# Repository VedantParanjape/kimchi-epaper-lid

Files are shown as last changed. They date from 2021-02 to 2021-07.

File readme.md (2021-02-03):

# kimχ micro lid KiCad project template

This template lets you create lid expansion boards for the [kimχ micro i.MX8M Mini SBC](https://labs.groupgets.com/kimchi-micro).

This project should include everything you need to make an expansion board, including an eeprom
that can be used to identify your lid and automatically load the correct configuration files (with
some software work to support this).

## How to use this project

This project is to be used with KiCad's "New Project from Template" function.

### Download with GitHub

On GitHub you can select Clone or Download -> Download Zip. Then expand the archive and move it into your user's KiCad templates directory: `$HOME/kicad/template/`. You may have to create this directory if it doesn't exist.

In KiCad, select File > New Project > New Project From Template, and select User Templates. You can then select the kimχ micro - LID project in this list.

### Clone with GitHub

Alternatively, you can create a new GitHub project from this template by selecting Use This Template, above. From there you clone the new project locally and open it directly with KiCad.

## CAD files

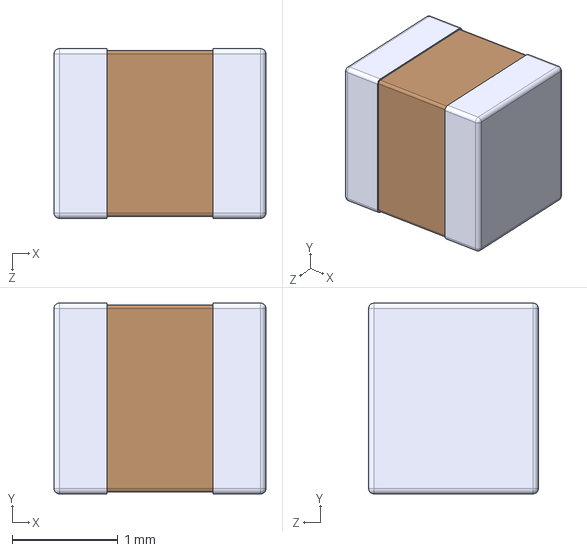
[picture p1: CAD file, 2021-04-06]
component-libraries/LBM2016T680J/LBM2016T680J.step
2.00 x 1.80 x 1.60 mm

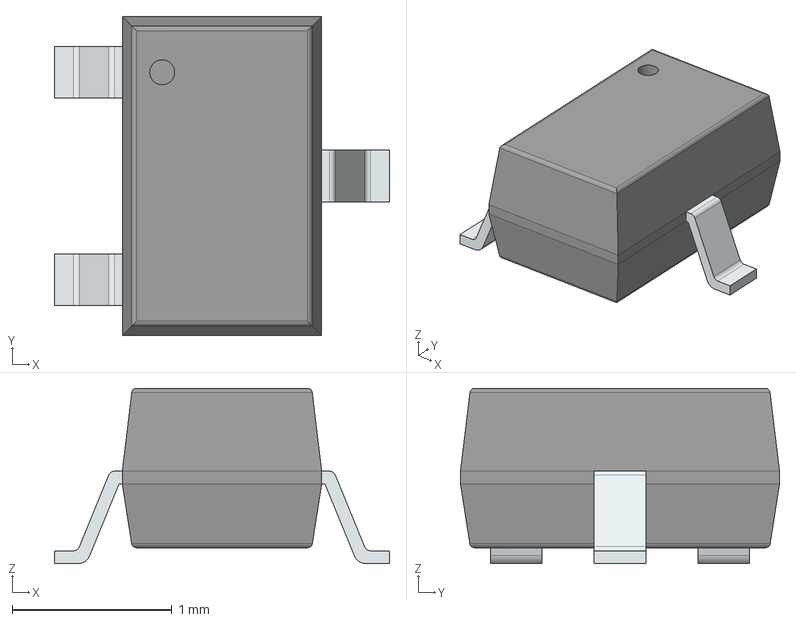
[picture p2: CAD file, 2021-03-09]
component-libraries/SI1308EDL-T1-BE3/SI1308EDL-T1-BE3.stp
2.10 x 2.00 x 1.10 mm
PinsArrayL
FilletPinR

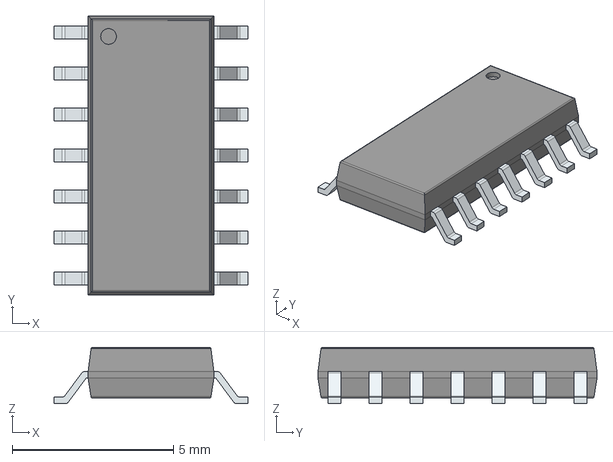
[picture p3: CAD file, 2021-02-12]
component-libraries/TXS0104ED/TXS0104ED.stp
6.00 x 8.65 x 1.75 mm
PinsArrayLR

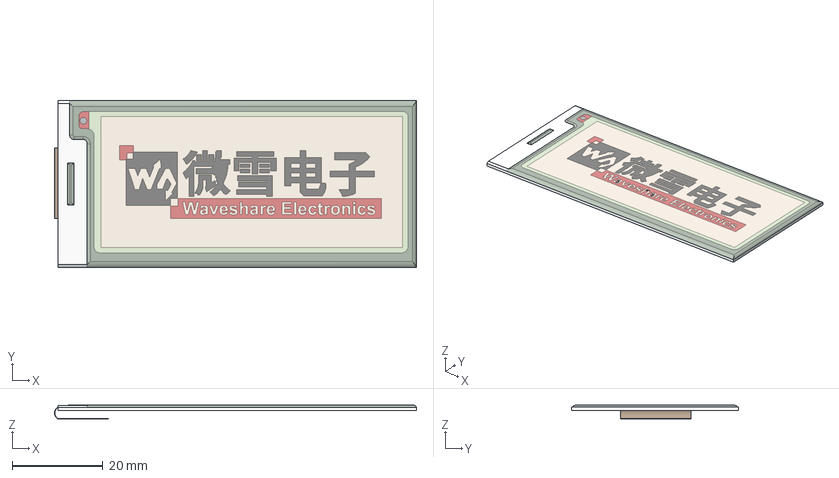
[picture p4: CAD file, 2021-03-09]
component-libraries/EPAPER_FPC_CONNECTOR/Waveshare 2.9 (B) E-ink - Display Folded.stp
79.9 x 36.8 x 3.17 mm

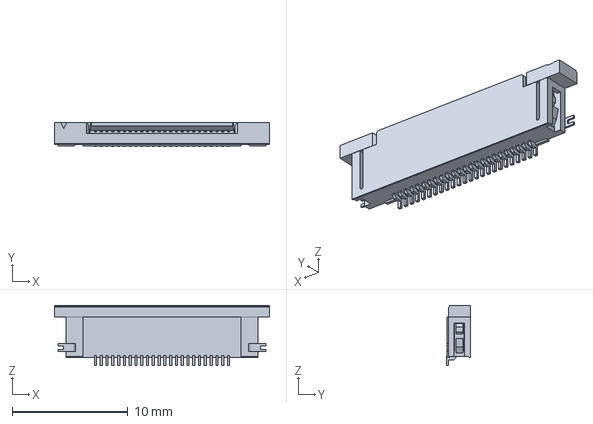
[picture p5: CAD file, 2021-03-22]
component-libraries/EPAPER_FPC_CONNECTOR/524352471.stp
18.6 x 2.05 x 5.20 mm

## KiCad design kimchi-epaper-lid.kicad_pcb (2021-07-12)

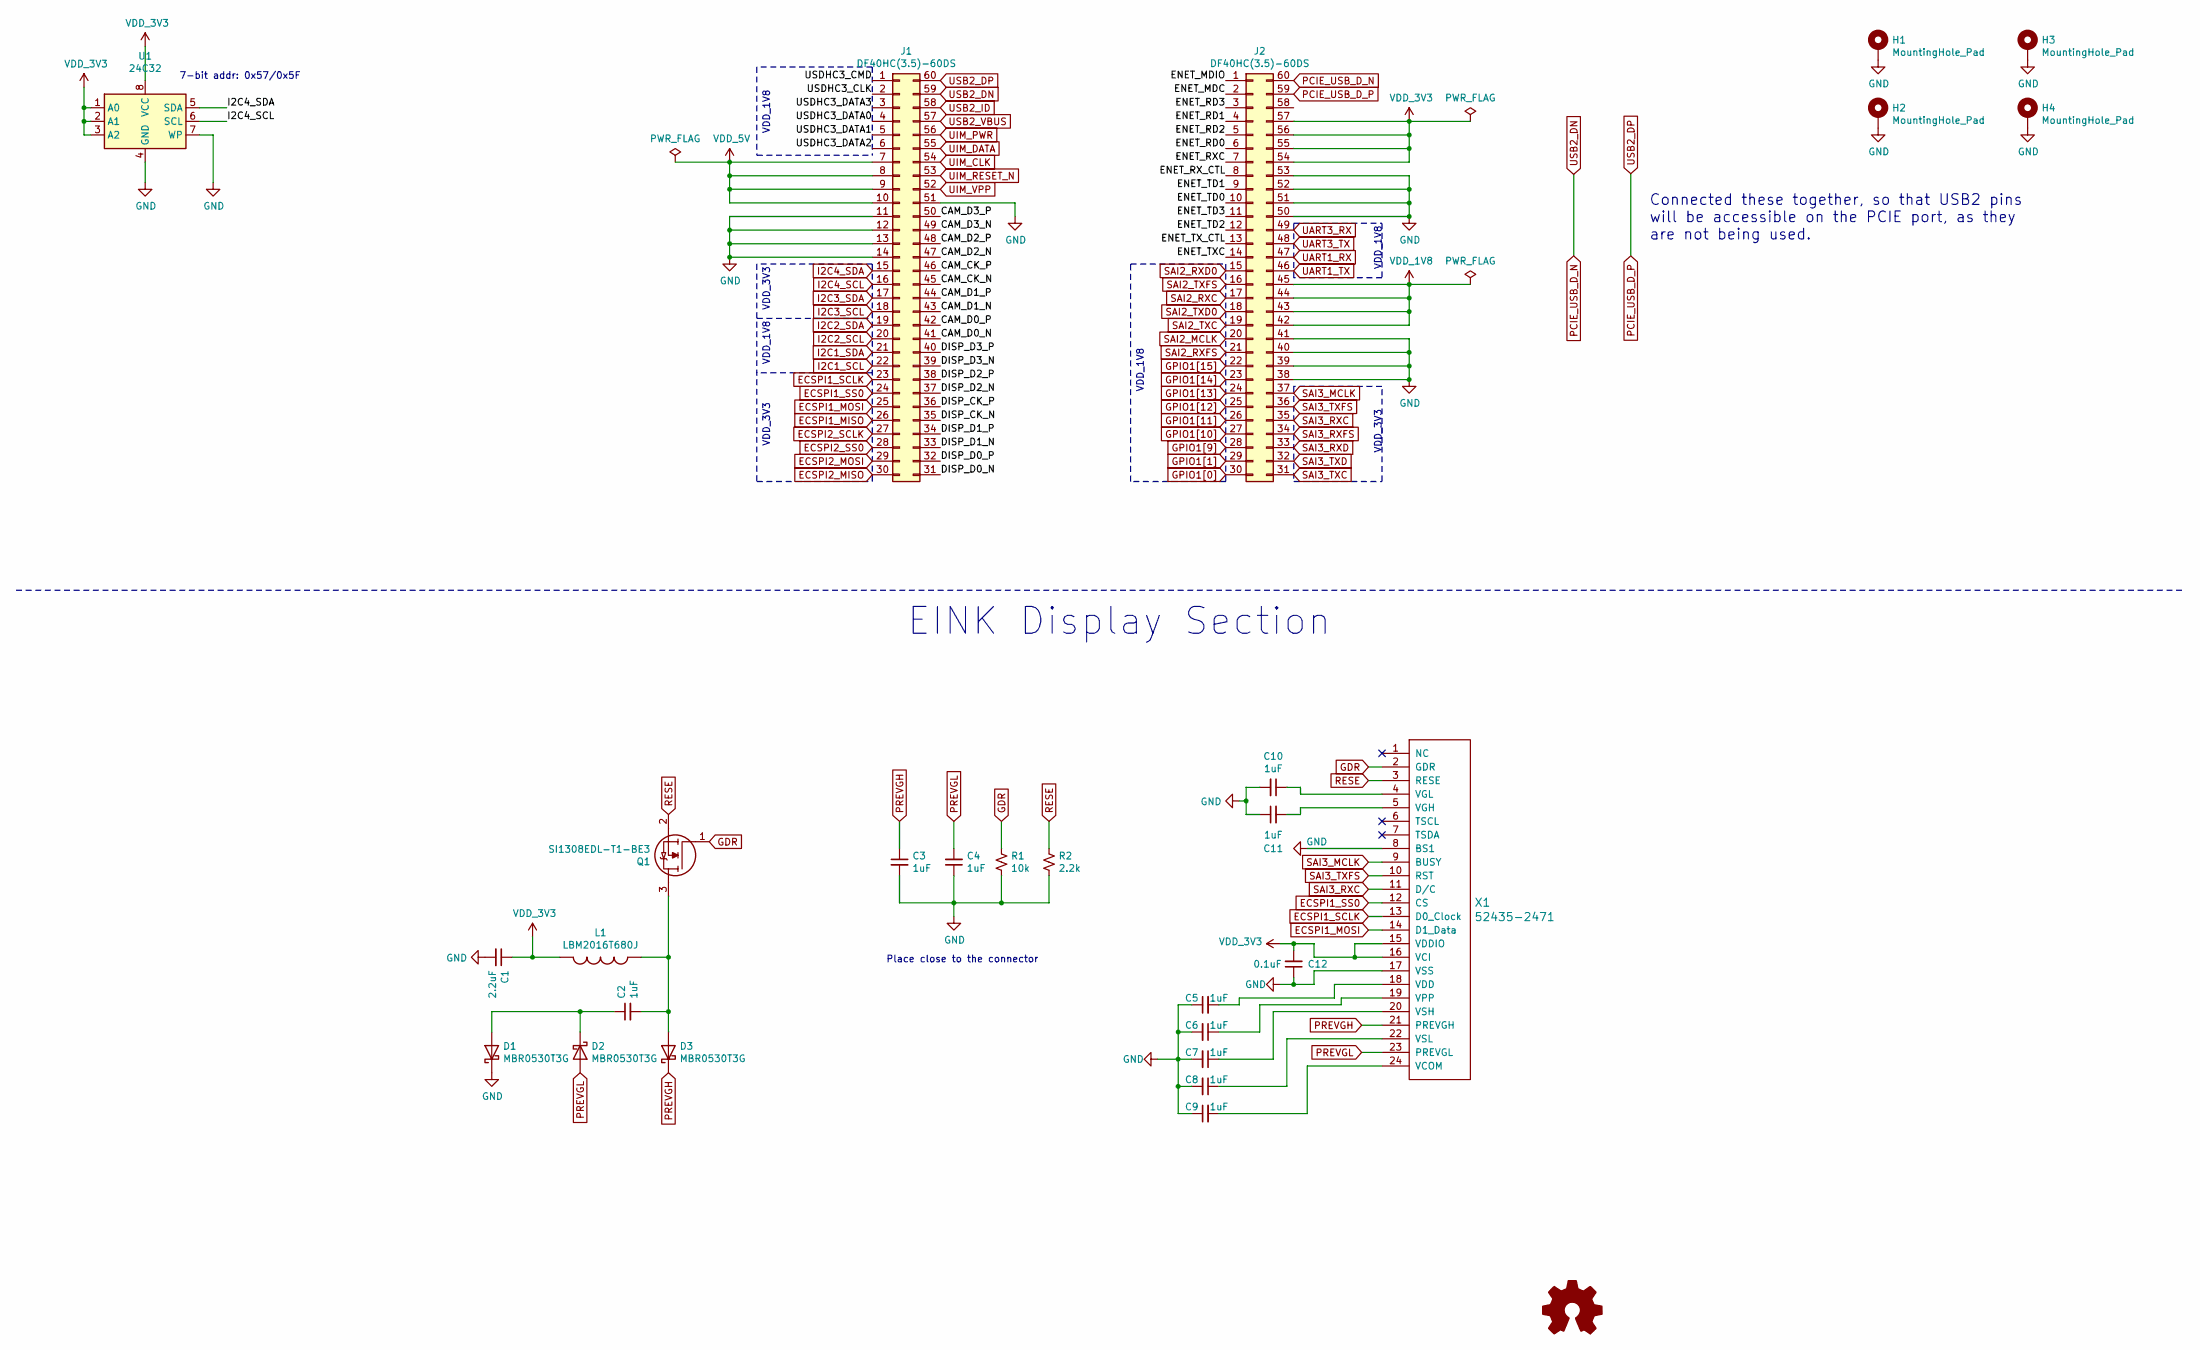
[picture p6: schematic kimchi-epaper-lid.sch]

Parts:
C1: 2.2uF; C_0603_1608Metric
C2, C3, C4, C5, C6, C7, C8, C9, C10, C11: 1uF; C_0603_1608Metric
C12: 0.1uF; C_0603_1608Metric
D1, D2, D3: MBR0530T3G; D_SOD-123
H1, H2, H3, H4: MountingHole_Pad; MountingHole_3mm_Pad
J1, J2: DF40HC(3.5)-60DS
L1: LBM2016T680J; INDC2016X180N
LOGO1: Logo_Open_Hardware_Small; OSHW-Logo_5.7x6mm_SilkScreen
Q1: SI1308EDL-T1-BE3; SOT65P210X110-3N; Manufacturer_Part_Number SI1308EDL-T1-BE3; Mouser Part Number 78-SI1308EDL-T1-BE3
R1: 10k; R_0603_1608Metric
R2: 2.2k; R_0603_1608Metric
U1: 24C32; DFN-8-1EP_3x2mm_P0.5mm_EP1.36x1.46mm; Part M24C32-FMC6TG
X1: 52435-2471; MOLEX_52435-2471

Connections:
/CAM_CK_N: J1.45
/CAM_CK_P: J1.46
/CAM_D0_N: J1.41
/CAM_D0_P: J1.42
/CAM_D1_N: J1.43
/CAM_D1_P: J1.44
/CAM_D2_N: J1.47
/CAM_D2_P: J1.48
/CAM_D3_N: J1.49
/CAM_D3_P: J1.50
/DISP_CK_N: J1.35
/DISP_CK_P: J1.36
/DISP_D0_N: J1.31
/DISP_D0_P: J1.32
/DISP_D1_N: J1.33
/DISP_D1_P: J1.34
/DISP_D2_N: J1.37
/DISP_D2_P: J1.38
/DISP_D3_N: J1.39
/DISP_D3_P: J1.40
/ENET_MDC: J2.2
/ENET_MDIO: J2.1
/ENET_RD0: J2.6
/ENET_RD1: J2.4
/ENET_RD2: J2.5
/ENET_RD3: J2.3
/ENET_RXC: J2.7
/ENET_RX_CTL: J2.8
/ENET_TD0: J2.10
/ENET_TD1: J2.9
/ENET_TD2: J2.12
/ENET_TD3: J2.11
/ENET_TXC: J2.14
/ENET_TX_CTL: J2.13
/USDHC3_CLK: J1.2
/USDHC3_CMD: J1.1
/USDHC3_DATA0: J1.4
/USDHC3_DATA1: J1.5
/USDHC3_DATA2: J1.6
/USDHC3_DATA3: J1.3
ECSPI1_MISO: J1.26
ECSPI1_MOSI: J1.25, X1.14 (D1_Data)
ECSPI1_SCLK: J1.23, X1.13 (D0_Clock)
ECSPI1_SS0: J1.24, X1.12 (CS)
ECSPI2_MISO: J1.30
ECSPI2_MOSI: J1.29
ECSPI2_SCLK: J1.27
ECSPI2_SS0: J1.28
GDR: Q1.1, R1.1, X1.2 (GDR)
GND: C1.2, C3.2, C4.1, C5.1, C6.2, C7.2, C8.2, C9.1, C10.2, C11.1, C12.1, D1.1 (K), H1.1, H2.1, H3.1, H4.1, J1.11, J1.12, J1.13, J1.14, J1.51, J2.38, J2.39, J2.40, J2.41, J2.50, J2.51, J2.52, J2.53, R1.2, R2.2, U1.4 (GND), U1.7 (WP), X1.8 (BS1), X1.17 (VSS)
GPIO1[0]: J2.30
GPIO1[1]: J2.29
GPIO1[9]: J2.28
GPIO1[10]: J2.27
GPIO1[11]: J2.26
GPIO1[12]: J2.25
GPIO1[13]: J2.24
GPIO1[14]: J2.23
GPIO1[15]: J2.22
I2C1_SCL: J1.22
I2C1_SDA: J1.21
I2C2_SCL: J1.20
I2C2_SDA: J1.19
I2C3_SCL: J1.18
I2C3_SDA: J1.17
I2C4_SCL: J1.16, U1.6 (SCL)
I2C4_SDA: J1.15, U1.5 (SDA)
unnamed: C2.1, D1.2 (A), D2.1 (K)
unnamed: C2.2, D3.2 (A), L1.2, Q1.3
unnamed: C5.2, X1.18 (VDD)
unnamed: C6.1, X1.19 (VPP)
unnamed: C7.1, X1.20 (VSH)
unnamed: C8.1, X1.22 (VSL)
unnamed: C9.2, X1.24 (VCOM)
unnamed: C10.1, X1.4 (VGL)
unnamed: C11.2, X1.5 (VGH)
PCIE_USB_D_N: J1.59, J2.60
PCIE_USB_D_P: J1.60, J2.59
PREVGH: C3.1, D3.1 (K), X1.21 (PREVGH)
PREVGL: C4.2, D2.2 (A), X1.23 (PREVGL)
RESE: Q1.2, R2.1, X1.3 (RESE)
SAI2_MCLK: J2.20
SAI2_RXC: J2.17
SAI2_RXD0: J2.15
SAI2_RXFS: J2.21
SAI2_TXC: J2.19
SAI2_TXD0: J2.18
SAI2_TXFS: J2.16
SAI3_MCLK: J2.37, X1.9 (BUSY)
SAI3_RXC: J2.35, X1.11 (D/C)
SAI3_RXD: J2.33
SAI3_RXFS: J2.34
SAI3_TXC: J2.31
SAI3_TXD: J2.32
SAI3_TXFS: J2.36, X1.10 (RST)
UART1_RX: J2.47
UART1_TX: J2.46
UART3_RX: J2.49
UART3_TX: J2.48
UIM_CLK: J1.54
UIM_DATA: J1.55
UIM_PWR: J1.56
UIM_RESET_N: J1.53
UIM_VPP: J1.52
USB2_ID: J1.58
USB2_VBUS: J1.57
VDD_1V8: J2.42, J2.43, J2.44, J2.45
VDD_3V3: C1.1, C12.2, J2.54, J2.55, J2.56, J2.57, L1.1, U1.1 (A0), U1.2 (A1), U1.3 (A2), U1.8 (VCC), X1.15 (VDDIO), X1.16 (VCI)
VDD_5V: J1.7, J1.8, J1.9, J1.10

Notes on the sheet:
7-bit addr: 0x57/0x5F
VDD_1V8
VDD_3V3
EINK Display Section
Place close to the connector
Connected these together, so that USB2 pins will be accessible on the PCIE port, as they are not being used.

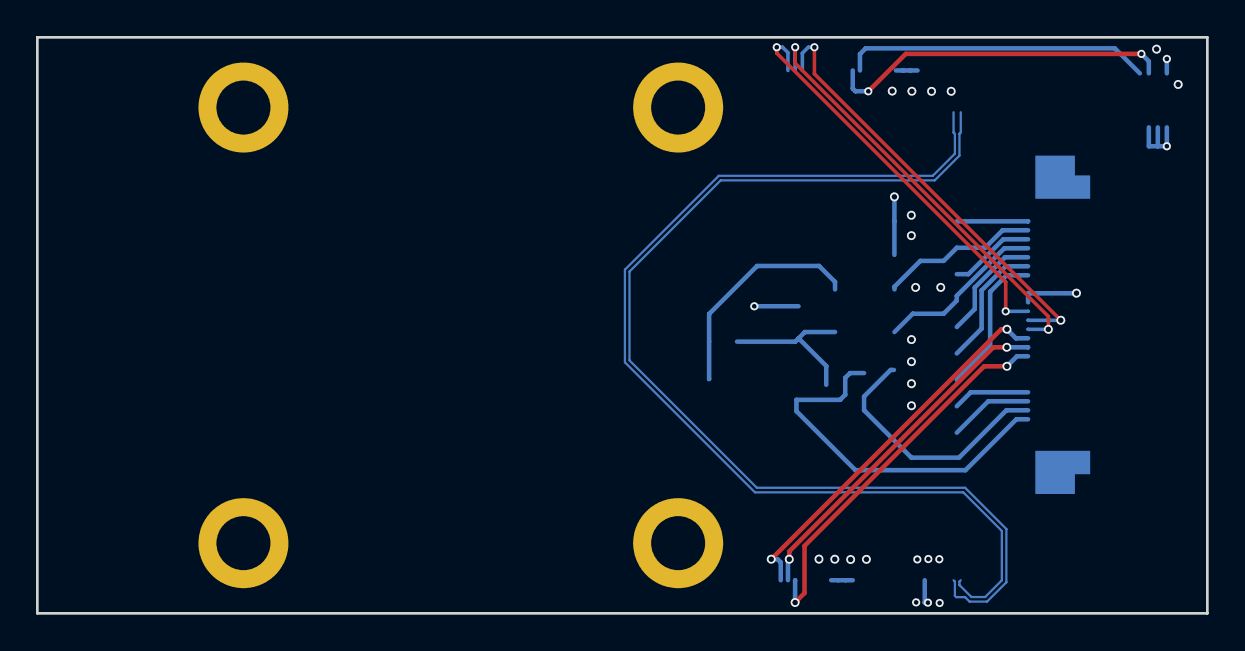
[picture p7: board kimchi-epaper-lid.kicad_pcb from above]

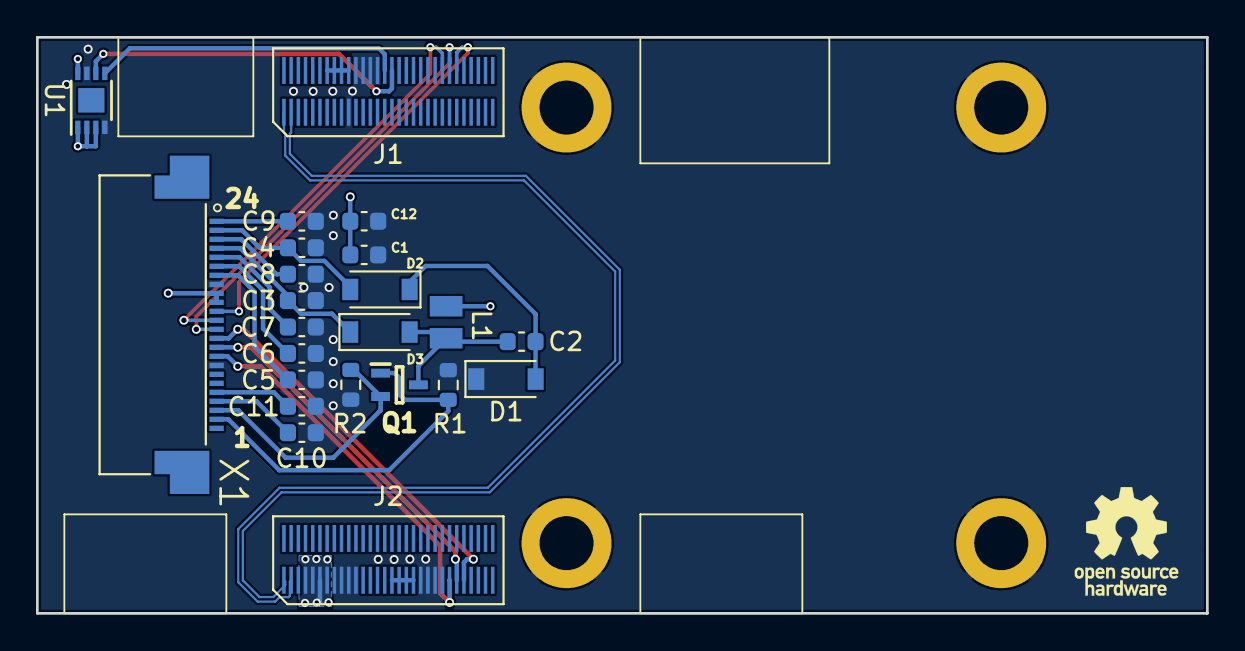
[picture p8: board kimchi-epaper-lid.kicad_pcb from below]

Board: 4 copper layers, 65.0 x 32.0 mm, 28 parts (24 on the bottom side), 27 nets.

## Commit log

2021-02-12 Partially completed schematics of the lid
    [TXS0104ED.stp, kimchi-epaper-lid.kicad_pcb, kimchi-epaper-lid.sch]
2021-03-09 prouting a few components and updated position
    [NLV32T-680J-EF.stp, SI1308EDL-T1-BE3.stp, Waveshare 2.9 (B) E-ink - Display Folded.stp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]
2021-03-15 Completed routing
    [kimchi-epaper-lid.kicad_pcb]
2021-03-21 Updated routing
    [kimchi-epaper-lid-B_Cu.gbr, kimchi-epaper-lid-B_Mask.gbr, kimchi-epaper-lid-B_Paste.gbr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]
2021-03-22 Fixed issues with routing
    [kimchi-epaper-lid.kicad_pcb, kimchi-epaper-lid.sch]
2021-03-22 Added 3d model of fpc connector
    [524352471.stp, kimchi-epaper-lid.kicad_pcb]
2021-04-06 Replaced inductor and completed routing (acq review)
    [LBM2016T680J.step, NLV32T-680J-EF.stp, kimchi-epaper-lid.kicad_pcb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]
2021-07-12 Fixed mistake in mosfet schematics
    [kimchi-epaper-lid-B_Cu.gbr, kimchi-epaper-lid-B_Mask.gbr, kimchi-epaper-lid-B_Paste.gbr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]

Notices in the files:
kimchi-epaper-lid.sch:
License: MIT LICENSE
